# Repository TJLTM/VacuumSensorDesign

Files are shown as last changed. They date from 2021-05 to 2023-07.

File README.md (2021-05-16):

# VacuumSensorDesign
A Vacuum Sesnor Design for Automotive applications
I'm too lazy to really write too much here. Basically in my search for telemtry from older cars for tuning and diagnostic purposes, I needed a manifold Vacuum Sensor that can be connected to SBC/MCU. Looking in the marketplace for equiv sensors there are few. and even looking in catalogs for raw sensors for this application there wasn't much in the way of vacuum sensors. the only equiv i found was the https://www.glowshiftdirect.com/vacuum-gauges/ looking at this one after i spent months searching for something i could build myself. shows that i basically picked the same sensor but from honeywell instead of NXP. Plus side for the honeywell sensor is that it doesn't require special housing and mechaincal design to mount the board and have a good seal to the sensor so it can go into a generic enclosure. 

Basic specs
1. Read a vacuum signal from +/- 30psi (+/- 206KPa)
2. Output an protected MCU ADC value (0-4.5v ~2.5v for zero reading ie at atmospheric pressure)  
5. With some Re-calibration and tweaks this design should work for 3.3 ADC inputs 
6. Run on car voltages (12 volt neg ground) 
7. ability to be re-caled in the field if need be

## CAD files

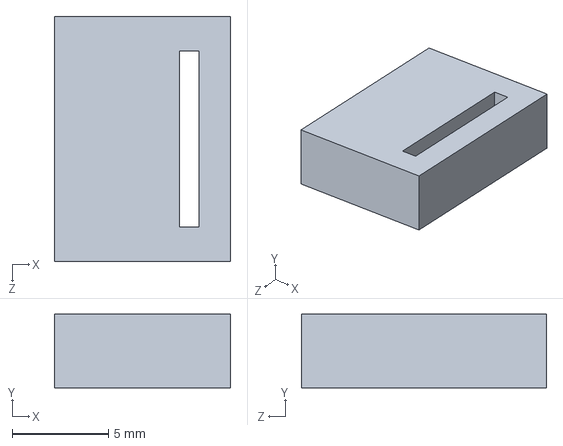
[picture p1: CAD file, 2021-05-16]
CAD/vacuum sensor spacer.SLDPRT
9.14 x 3.81 x 12.7 mm

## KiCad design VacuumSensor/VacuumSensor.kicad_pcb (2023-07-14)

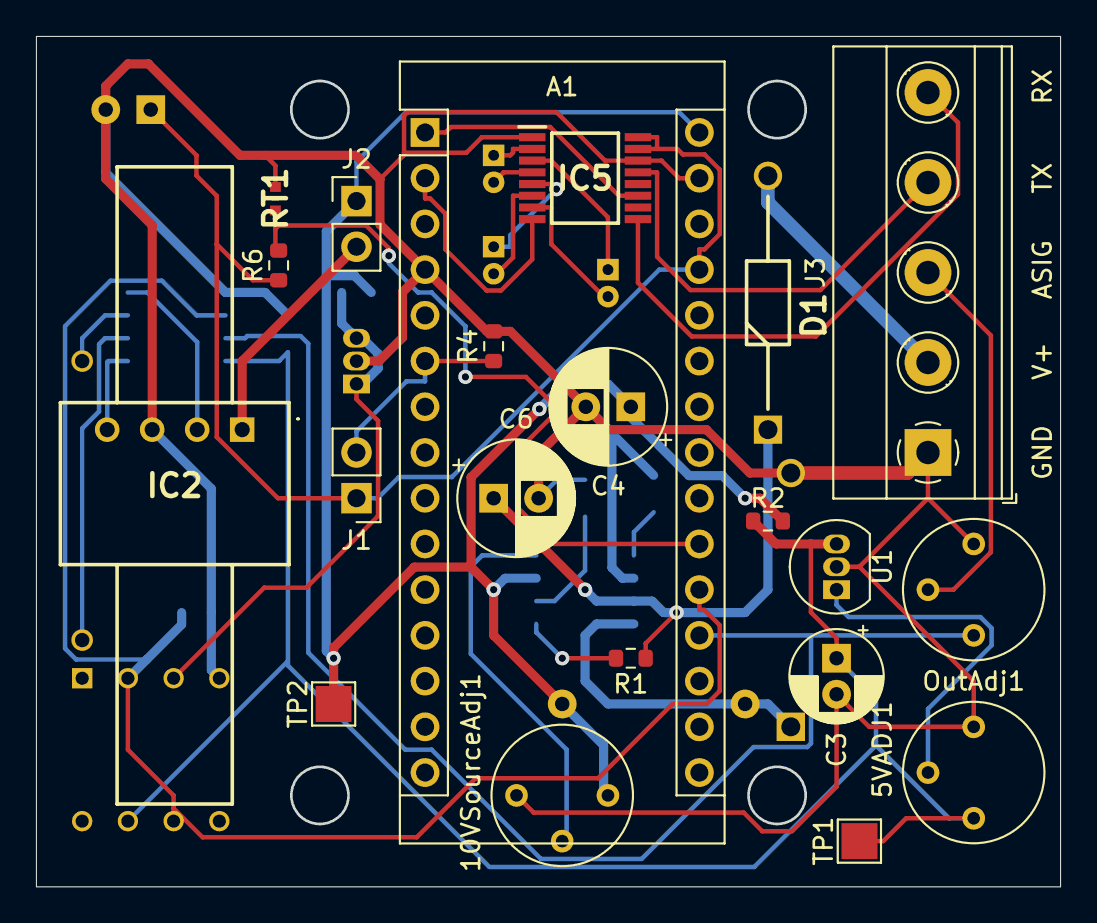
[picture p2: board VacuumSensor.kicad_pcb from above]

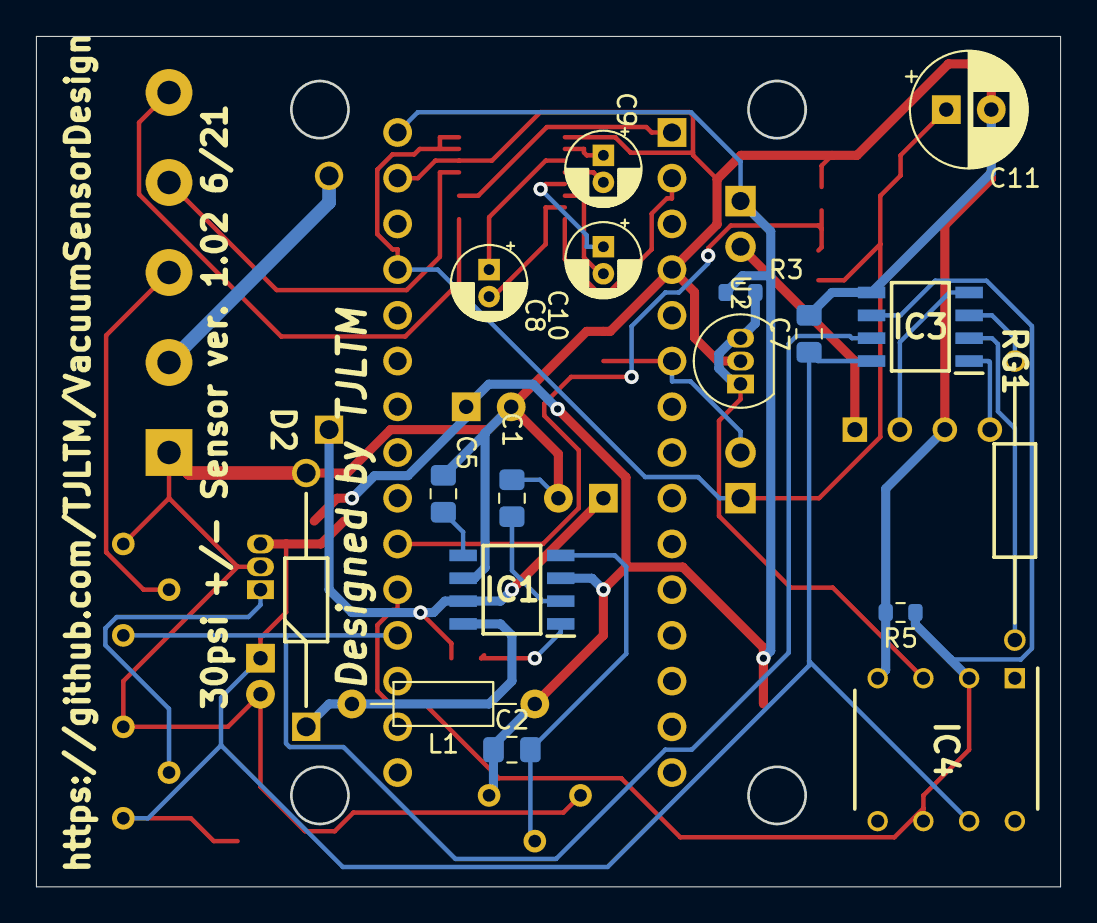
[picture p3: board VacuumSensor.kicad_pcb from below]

Board: 2 copper layers, 56.9 x 47.2 mm, 38 parts (17 on the bottom side), 33 nets.

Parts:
5VADJ1: 20k; Potentiometer_Bourns_3339P_Vertical
10VSourceAdj1: 10k; Potentiometer_Bourns_3339P_Vertical
A1: Arduino_Nano_v3.x; Arduino_Nano
C1, C5: 0.1uF; C_0805_2012Metric_Pad1.15x1.40mm_HandSolder
C2: 33nF; C_0805_2012Metric_Pad1.15x1.40mm_HandSolder
C3: 1uF; CP_Radial_D5.0mm_P2.00mm
C4: 120uf; CP_Radial_D6.3mm_P2.50mm
C6: 68uF; CP_Radial_D6.3mm_P2.50mm
C7: 100nF; C_0805_2012Metric_Pad1.15x1.40mm_HandSolder
C8, C9, C10: 0.22uF; CP_Radial_D4.0mm_P1.50mm
C11: 0.1uF; CP_Radial_D6.3mm_P2.50mm
D1, D2: 1N5817; DIOAD1414W86L464D238
IC1: LM2597MX-ADJ_NOPB; SOIC127P600X175-8N
IC2: 24PCDFA6D
IC3: INA849DR; SOIC127P600X175-8N
IC4: TL071CP; DIP794W53P254L959H508Q8N
IC5: SP3220EBEY-L_TR; SOP65P640X120-16N
J1, J2: Conn_01x02; PinHeader_1x02_P2.54mm_Vertical
J3: Screw_Terminal_01x05; TerminalBlock_Phoenix_MKDS-1,5-5_1x05_P5.00mm_Horizontal
L1: L; L_Axial_L5.3mm_D2.2mm_P10.16mm_Horizontal_Vishay_IM-1
OutAdj1: 1M; Potentiometer_Bourns_3339P_Vertical
R1, R6: 10k; R_0603_1608Metric
R2, R3: 1k; R_0603_1608Metric
R4: 20k; R_0603_1608Metric
R5: 10M; R_0603_1608Metric
RG1: YR1B665RCC; RESAD1550W60L630D230
RT1: NTCSP103JF103FT1S; THRMC1005X55N
TP1, TP2: TestPoint; TestPoint_Pad_2.0x2.0mm
U1, U2: TL431LP; TO-92_Inline

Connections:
+5V: 5VADJ1.1, C3.1, C7.1, IC3.8, IC4.7, R2.2, TP1.1, U1.3
+10V: 10VSourceAdj1.1, A1.30, C2.1, C4.1, IC1.3, J2.1, L1.1, R2.1, R3.1, TP2.1
+VDC: C6.1, D1.1, IC1.7, R1.1
GND: 5VADJ1.3, 10VSourceAdj1.3, A1.4, A1.29, C1.2, C3.2, C4.2, C5.2, C6.2, C7.2, C11.2, D2.2, IC1.6, IC2.3, IC3.5, IC4.4, IC5.1, IC5.14, J3.1, OutAdj1.3, R4.2, R5.2, RT1.2, U1.2, U2.2
unnamed: 5VADJ1.2, U1.1
unnamed: 10VSourceAdj1.2, C2.2, IC1.4
unnamed: A1.1, IC5.11
unnamed: A1.2, IC5.8
unnamed: A1.6, J1.2, R4.1
unnamed: A1.19, IC3.7, OutAdj1.1
unnamed: A1.20, IC3.6, IC4.2, IC4.6, R5.1
unnamed: A1.21, R6.2, RT1.1
unnamed: A1.27, C11.1, IC5.15, IC5.16, J1.1, R6.1
unnamed: C1.1, IC1.2
unnamed: C5.1, IC1.5
unnamed: C8.1, IC5.3
unnamed: C8.2, IC5.7
unnamed: C9.1, IC5.2
unnamed: C9.2, IC5.4
unnamed: C10.1, IC5.5
unnamed: C10.2, IC5.6
unnamed: D1.2, J3.2
unnamed: D2.1, IC1.8, L1.2
unnamed: IC1.1, R1.2
unnamed: IC2.1, J2.2
unnamed: IC2.2, IC3.4
unnamed: IC2.4, IC3.1
unnamed: IC3.2, RG1.2
unnamed: IC3.3, RG1.1
unnamed: IC4.3, R3.2, U2.1, U2.3
unnamed: IC5.9, J3.5
unnamed: IC5.13, J3.4
unnamed: J3.3, OutAdj1.2

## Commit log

2021-05-16 pushing up my current design and fab files. Code and Docs to follow.
    [VacuumSensor-B_Cu.gbr, VacuumSensor-B_Mask.gbr, VacuumSensor-B_Paste.gbr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]
2021-05-16 Initial Code for Arduino. needs to be re verified for calibration.
2021-05-16 adding cad files for a spacer that goes under Honeywell 24PCDFA6D when mounting onto the PCB
    [vacuum sensor spacer.SLDPRT, vacuum sensor spacer.STL]
2021-05-26 1.02 update removed the unity gain output op amp and Gain trim pot and replaced it witha 0.1% 665 ohm resistor for the instrumentation amp. simplified the voltage reference and 5v circuits. Added an 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
    [VacuumSensor.kicad_pcb, VacuumSensor.sch]
2021-05-26 adding the Fab Files for 1.02
    [VacuumSensor-B_Cu.gbr, VacuumSensor-B_Mask.gbr, VacuumSensor-B_Paste.gbr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]
2022-01-15 upgrade to 6.0 kicad
    [VacuumSensor.kicad_pcb, VacuumSensor.kicad_sch, VacuumSensor.sch]
2022-01-15 keeping the original single board design and adding a second one with a new base board that will use the same dual sensor board as the AMS
    [VacuumSensor.kicad_pcb, VacuumSensor.kicad_sch, VacuumSensor.sch]
2022-01-15 adding the AMS vac sensor board design here.
    [AMS-Vacuum-Sensor.kicad_pcb, AMS-Vacuum-Sensor.kicad_sch]
2022-02-18 adding the new fab files for AMS board
    [AMS-Vacuum-Sensor-B_Cu.gbr, AMS-Vacuum-Sensor-B_Mask.gbr, AMS-Vacuum-Sensor-B_Paste.gbr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]
2022-02-18 removing old fab files for other design
    [VacuumSensor-B_Cu.gbr, VacuumSensor-B_Mask.gbr, VacuumSensor-B_Paste.gbr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]
2022-02-20 cleaning up the sensor designs because they where a mess and i'm going to make two different ones one that is a single board and one that is a carrier for the AMS dual version
    [AMS-Vacuum-Sensor.kicad_pcb, VacuumSensor.kicad_pcb, VacuumSensor.kicad_sch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]
2022-02-20 initial for AMS base Carrier
    [AMS-Vacuum-Sensor-Carrier.kicad_pcb, AMS-Vacuum-Sensor-Carrier.kicad_sch]
2022-02-20 don't know why git is having an issue with this file.
    [vacuum sensor spacer.STL]
2023-07-14 updating all the kicad files to 7.0
    [AMS-Vacuum-Sensor-Carrier.kicad_pcb, AMS-Vacuum-Sensor-Carrier.kicad_sch, AMS-Vacuum-Sensor.kicad_pcb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]
2023-08-22 * removing the other designs * fixing up the original design
    [AMS-Vacuum-Sensor-Carrier.kicad_pcb, AMS-Vacuum-Sensor-Carrier.kicad_sch, AMS-Vacuum-Sensor.kicad_pcb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]
2023-08-22 moving and reorganizing
    [AMS-Vacuum-Sensor-B_Cu.gbr, AMS-Vacuum-Sensor-B_Mask.gbr, AMS-Vacuum-Sensor-B_Paste.gbr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]
